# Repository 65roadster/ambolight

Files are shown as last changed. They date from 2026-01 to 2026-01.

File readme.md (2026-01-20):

# Ray's Retirement Nest Egg Calculator

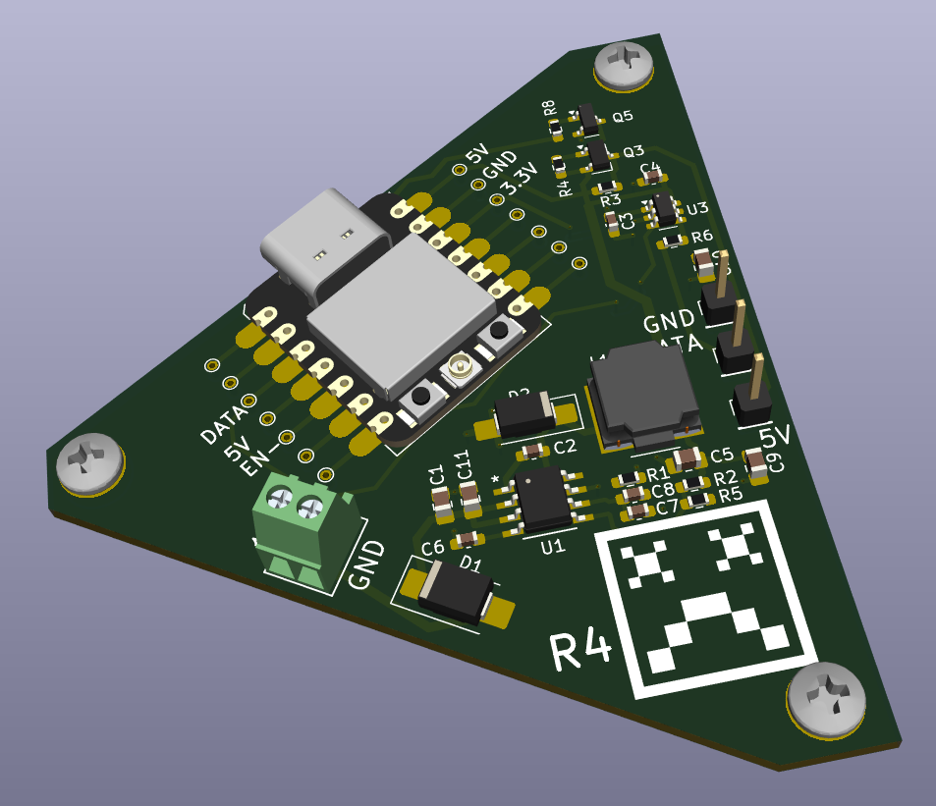
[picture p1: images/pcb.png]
<br />

## Overview
Drew bought an old ambulance to fix up into an RV. I wanted to contribute so I created an ESP32 controlled light.

The light has a ring of around 80- addressable RGBW LEDs.

The board accomodates 12V to 5V @ 3A switching supply to drive the LEDs using the TPS54331DDAR.

The ESP32 is programmed with WLED. 10 of these are controlled by Home Assistant.

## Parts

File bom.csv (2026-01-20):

Reference | Value | Datasheet | Footprint | Qty | DNP
C1,C7 | 22u | https://www.digikey.com/en/products/detail/samsung-electro-mechanics/CL31A226MOCLNNC/3888386 | Capacitor_SMD:C_1210_3225Metric_Pad1.33x2.70mm_HandSolder | 2
C2 | 1u | https://www.digikey.com/en/products/detail/samsung-electro-mechanics/CL31A226MOCLNNC/3888386 | Capacitor_SMD:C_1210_3225Metric_Pad1.33x2.70mm_HandSolder | 1
D2,D3,D4,D5,D6,D7,D8,D9,D10,D11,D12,D13,D14,D15,D16,D17,D18,D19,D20,D21,D22,D23,D24,D25 | IN-PI4818QAS5R5G5BPW | https://www.digikey.com/en/products/detail/inolux/in-pi4818qas5r5g5bpw/16964400 | 1-rjc-rv:LED_IN-PI42TASPRPGPB | 24
D26 | SMCJ28CA | https://www.digikey.com/en/products/detail/taiwan-semiconductor-corporation/SMCJ28CA/3042735 | Diode_SMD:D_SMC_Handsoldering | 1
J1,J2,J3 | 2061-602/998-404 | 2061-602/998-404 | 1-rjc-rv:WAGO_CONN2_2061-602_998-404_WAG | 3
Q1,Q3 | DMP3099L | https://www.digikey.com/en/products/detail/diodes-incorporated/DMP3099L-7/4471075 | Package_TO_SOT_SMD:TSOT-23_HandSoldering | 2
Q2 | BSS138-7-F | https://www.digikey.com/en/products/detail/diodes-incorporated/BSS138-7-F/717723 | Package_TO_SOT_SMD:TSOT-23_HandSoldering | 1
Q5 | MMBT3904 | https://www.digikey.com/en/products/detail/nexperia-usa-inc/MMBT3904-215/1156599 | Package_TO_SOT_SMD:SOT-23 | 1
R1,R2,R3,R18 | 10k | ~ | Resistor_SMD:R_1206_3216Metric_Pad1.30x1.75mm_HandSolder | 4
R4,R8 | 100k | ~ | Resistor_SMD:R_1206_3216Metric_Pad1.30x1.75mm_HandSolder | 2
R5,R7 | 0 | ~ | Resistor_SMD:R_1206_3216Metric_Pad1.30x1.75mm_HandSolder | 2
R6 | 300 | ~ | Resistor_SMD:R_1206_3216Metric_Pad1.30x1.75mm_HandSolder | 1
R17 | 40.2k | ~ | Resistor_SMD:R_1206_3216Metric_Pad1.30x1.75mm_HandSolder | 1
TP1,TP2,TP3,TP4,TP5,TP6,TP7,TP8,TP9,TP10,TP11 | TestPoint | ~ | 1-rjc-rv:TP_SMT_25mil | 11
U1 | TLVM23615RDNR | https://www.digikey.com/en/products/detail/texas-instruments/TLVM23615RDNR/18716429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 | 1-rjc-rv:TLVM23615RDNR | 1
U2 | MOUDLE-SEEEDUINO-XIAO-ESP32C3 |  | KM-ESP-Kit:SeeedStudio-MOUDLE14P-SMD-2.54-21X17.8MM | 1

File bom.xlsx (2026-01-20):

Reference | Value | Qty | Price Ea | Extended Price | Datasheet | Footprint | Qty | DNP
C1,C7 | 22u | 0 | $0.15 | $0.00 | https://www.digikey.com/en/products/detail/samsung-electro-mechanics/CL31A226MOCLNNC/3888386 | Capacitor_SMD:C_1210_3225Metric_Pad1.33x2.70mm_HandSolder | 2
C2 | 1u | 1 | $0.01 | $0.01 | https://www.digikey.com/en/products/detail/samsung-electro-mechanics/CL31A226MOCLNNC/3888386 | Capacitor_SMD:C_1210_3225Metric_Pad1.33x2.70mm_HandSolder | 1
D2,D3,D4,D5,D6,D7,D8,D9,D10,D11,D12,D13,D14,D15,D16,D17,D18,D19,D20,D21,D22,D23,D24,D25 | IN-PI4818QAS5R5G5BPW | 24 | $0.41 | $9.84 | https://www.digikey.com/en/products/detail/inolux/in-pi4818qas5r5g5bpw/16964400 | 1-rjc-rv:LED_IN-PI42TASPRPGPB | 24
D26 | SMCJ28CA | 0 |  |  | https://www.digikey.com/en/products/detail/taiwan-semiconductor-corporation/SMCJ28CA/3042735 | Diode_SMD:D_SMC_Handsoldering | 1
J1,J2,J3 | 2061-602/998-404 | 0 |  |  | 2061-602/998-404 | 1-rjc-rv:WAGO_CONN2_2061-602_998-404_WAG | 3
Q1,Q3 | DMP3099L | 1 | $0.18 | $0.18 | https://www.digikey.com/en/products/detail/diodes-incorporated/DMP3099L-7/4471075 | Package_TO_SOT_SMD:TSOT-23_HandSoldering | 2
Q2 | BSS138-7-F | 1 | $0.11 | $0.11 | https://www.digikey.com/en/products/detail/diodes-incorporated/BSS138-7-F/717723 | Package_TO_SOT_SMD:TSOT-23_HandSoldering | 1
Q5 | MMBT3904 | 1 | $0.05 | $0.05 | https://www.digikey.com/en/products/detail/nexperia-usa-inc/MMBT3904-215/1156599 | Package_TO_SOT_SMD:SOT-23 | 1
R1,R2,R3,R18 | 10k | 5 | $0.01 | $0.05 | ~ | Resistor_SMD:R_1206_3216Metric_Pad1.30x1.75mm_HandSolder | 4
R4,R8 | 100k | 0 |  | $0.00 | ~ | Resistor_SMD:R_1206_3216Metric_Pad1.30x1.75mm_HandSolder | 2
R5,R7 | 0 | 0 |  | $0.00 | ~ | Resistor_SMD:R_1206_3216Metric_Pad1.30x1.75mm_HandSolder | 2
R6 | 300 | 0 |  | $0.00 | ~ | Resistor_SMD:R_1206_3216Metric_Pad1.30x1.75mm_HandSolder | 1
R17 | 40.2k | 0 |  | $0.00 | ~ | Resistor_SMD:R_1206_3216Metric_Pad1.30x1.75mm_HandSolder | 1
TP1,TP2,TP3,TP4,TP5,TP6,TP7,TP8,TP9,TP10,TP11 | TestPoint | 0 |  | $0.00 | ~ | 1-rjc-rv:TP_SMT_25mil | 11
U1 | TLVM23615RDNR | 0 |  | $0.00 | https://www.digikey.com/en/products/detail/texas-instruments/TLVM23615RDNR/18716429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 | 1-rjc-rv:TLVM23615RDNR | 1
U2 | MOUDLE-SEEEDUINO-XIAO-ESP32C3 | 1 | $5.00 | $5.00 |  | KM-ESP-Kit:SeeedStudio-MOUDLE14P-SMD-2.54-21X17.8MM | 1
 | PCB | 1 | $5.00 | $5.00
 |  |  | Total | $20.24

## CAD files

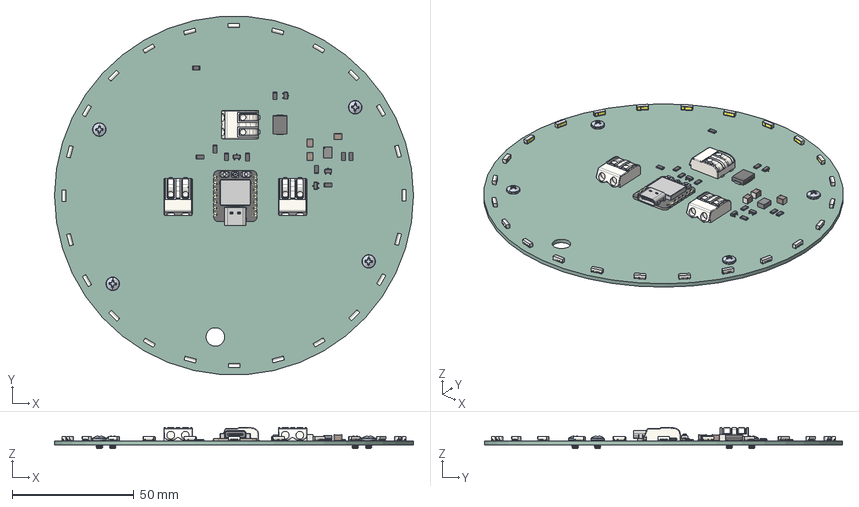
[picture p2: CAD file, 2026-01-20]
R0/abmolight.step
147.3 x 146.9 x 8.63 mm
2061-602/998-404 x 3
PI4818QAS5R5G5B5W x 24
90272A103 x 4
R_1206_3216Metric x 10
C_1210_3225Metric x 3
TSOT_23 x 3
TPSM365R6RDNR
SOT_23
Seeed Studio XIAO-ESP32-C3 v15
D_SMC
_autosave-rv_light_PCB

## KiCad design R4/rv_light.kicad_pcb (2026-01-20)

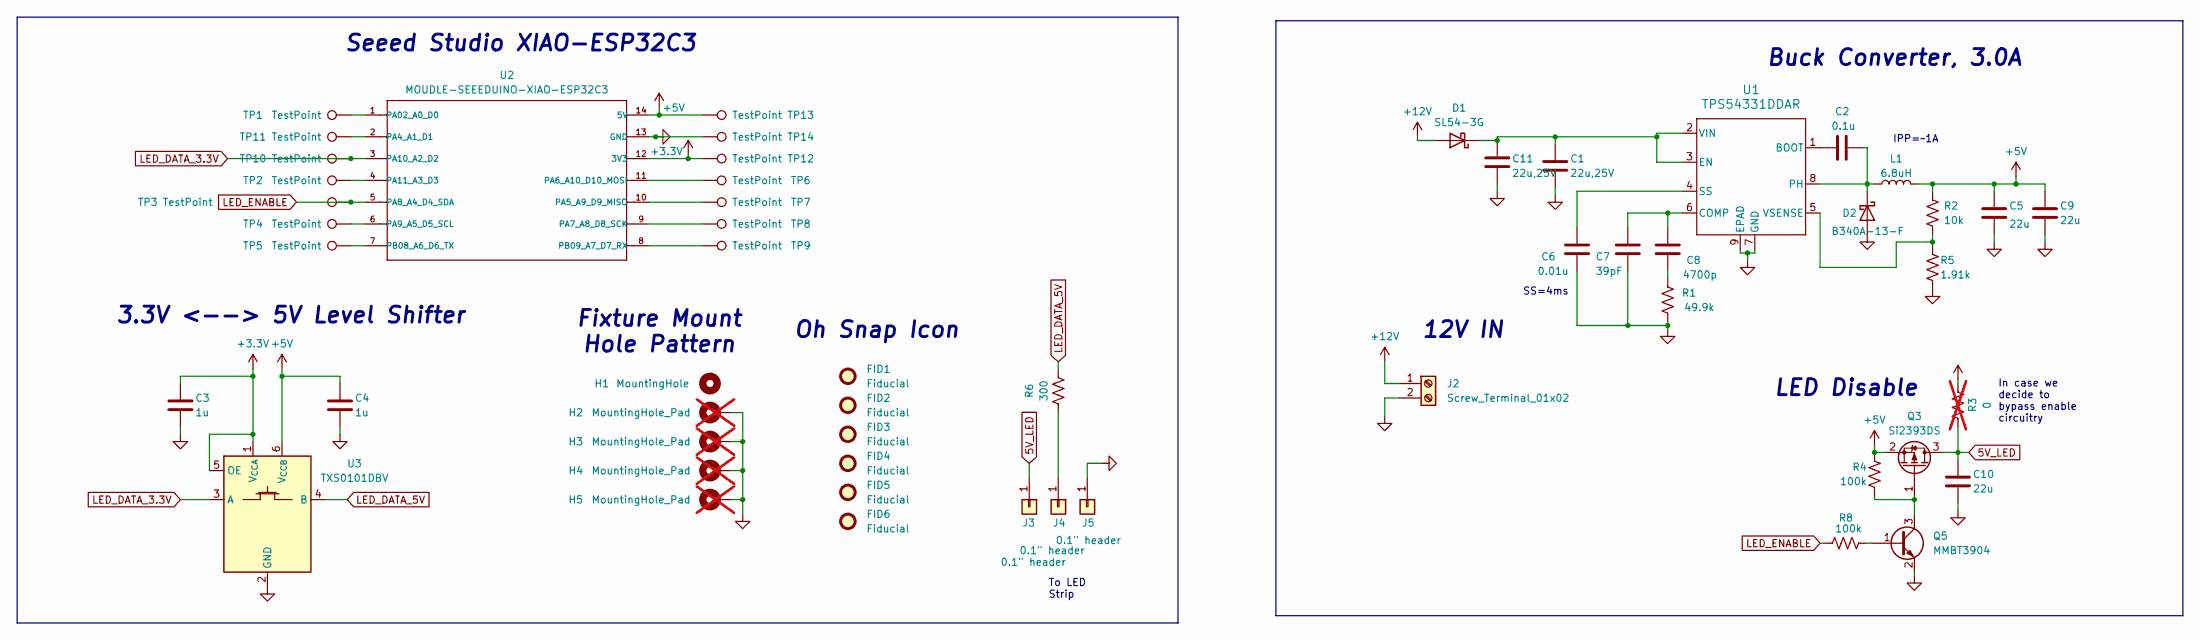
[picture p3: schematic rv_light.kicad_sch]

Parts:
C1, C11: 22u,25V; C_0805_2012Metric_Pad1.18x1.45mm_HandSolder
C2: 0.1u; C_0603_1608Metric_Pad1.08x0.95mm_HandSolder
C3, C4: 1u; C_0603_1608Metric_Pad1.08x0.95mm_HandSolder
C5, C9, C10: 22u; C_0805_2012Metric_Pad1.18x1.45mm_HandSolder
C6: 0.01u; C_0603_1608Metric_Pad1.08x0.95mm_HandSolder
C7: 39pF; C_0603_1608Metric_Pad1.08x0.95mm_HandSolder
C8: 4700p; C_0603_1608Metric_Pad1.08x0.95mm_HandSolder
D1: SL54-3G; D_SMB_Handsoldering
D2: B340A-13-F; D_SMA_Handsoldering
FID1, FID2, FID3, FID4, FID5, FID6: Fiducial; brokedit_icon_750x750
H1: MountingHole; Mount-Hole-#4-NoPad
H2, H3, H4, H5: MountingHole_Pad; Mount-Hole-#4; not fitted
J2: Screw_Terminal_01x02; CONN_OSTVN02A150_OST
J3, J4, J5: 0.1" header; PinHeader_1x01_P2.54mm_Vertical
L1: 6.8uH; L_Bourns_SRN8040TA
Q3: Si2393DS; TSOT-23
Q5: MMBT3904; SOT-23
R1: 49.9k; R_0603_1608Metric_Pad0.98x0.95mm_HandSolder
R2: 10k; R_0603_1608Metric_Pad0.98x0.95mm_HandSolder
R3: 0; R_0603_1608Metric_Pad0.98x0.95mm_HandSolder; not fitted
R4, R8: 100k; R_0603_1608Metric_Pad0.98x0.95mm_HandSolder
R5: 1.91k; R_0603_1608Metric_Pad0.98x0.95mm_HandSolder
R6: 300; R_0603_1608Metric_Pad0.98x0.95mm_HandSolder
TP1, TP2, TP3, TP4, TP5, TP6, TP7, TP8, TP9, TP10, TP11, TP12, TP13, TP14: TestPoint; TP_Wire-26ga
U1: TPS54331DDAR; DDA8_3X2P13-M
U2: MOUDLE-SEEEDUINO-XIAO-ESP32C3; SeeedStudio-MOUDLE14P-SMD-2.54-21X17.8MM
U3: TXS0101DBV; SOT-23-6

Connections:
5V_LED: C10.1, J3.1, Q3.3 (D), R3.1
+3.3V: C3.1, TP12.1, U2.12 (3V3), U3.1 (V_{CCA}), U3.5 (OE)
+5V: C4.1, C5.1, C9.1, L1.2, Q3.2 (S), R2.1, R3.2, R4.1, TP13.1, U2.14 (5V), U3.6 (V_{CCB})
+12V: D1.2 (A), J2.1
GND: C1.2, C3.2, C4.2, C5.2, C6.2, C7.2, C9.2, C10.2, C11.2, D2.2 (A), H2.1, H3.1, H4.1, H5.1, J2.2, J5.1, Q5.2 (E), R1.2, R5.2, TP14.1, U1.7 (GND), U1.9 (EPAD), U2.13 (GND), U3.2 (GND)
LED_DATA_3.3V: TP10.1, U2.3 (PA10_A2_D2), U3.3 (A)
LED_DATA_5V: R6.1, U3.4 (B)
LED_ENABLE: R8.1, TP3.1, U2.5 (PA8_A4_D4_SDA)
unnamed: C8.2, R1.1
unnamed: C1.1, C11.1, D1.1 (K), U1.2 (VIN), U1.3 (EN)
unnamed: C2.1, D2.1 (K), L1.1, U1.8 (PH)
unnamed: J4.1, R6.2
unnamed: Q3.1 (G), Q5.3 (C), R4.2
unnamed: Q5.1 (B), R8.2
unnamed: C2.2, U1.1 (BOOT)
unnamed: C7.1, C8.1, U1.6 (COMP)
unnamed: C6.1, U1.4 (SS)
unnamed: R2.2, R5.1, U1.5 (VSENSE)
unnamed: TP1.1, U2.1 (PA02_A0_D0)
unnamed: TP11.1, U2.2 (PA4_A1_D1)
unnamed: TP7.1, U2.10 (PA5_A9_D9_MISO)
unnamed: TP6.1, U2.11 (PA6_A10_D10_MOSI)
unnamed: TP8.1, U2.9 (PA7_A8_D8_SCK)
unnamed: TP4.1, U2.6 (PA9_A5_D5_SCL)
unnamed: TP2.1, U2.4 (PA11_A3_D3)
unnamed: TP5.1, U2.7 (PB08_A6_D6_TX)
unnamed: TP9.1, U2.8 (PB09_A7_D7_RX)

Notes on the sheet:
IPP=~1A
LED Disable
Buck Converter, 3.0A
Oh Snap Icon
In case we decide to bypass enable circuitry
12V IN
Seeed Studio XIAO-ESP32C3
SS=4ms
Fixture Mount Hole Pattern
To LED Strip
3.3V <--> 5V Level Shifter

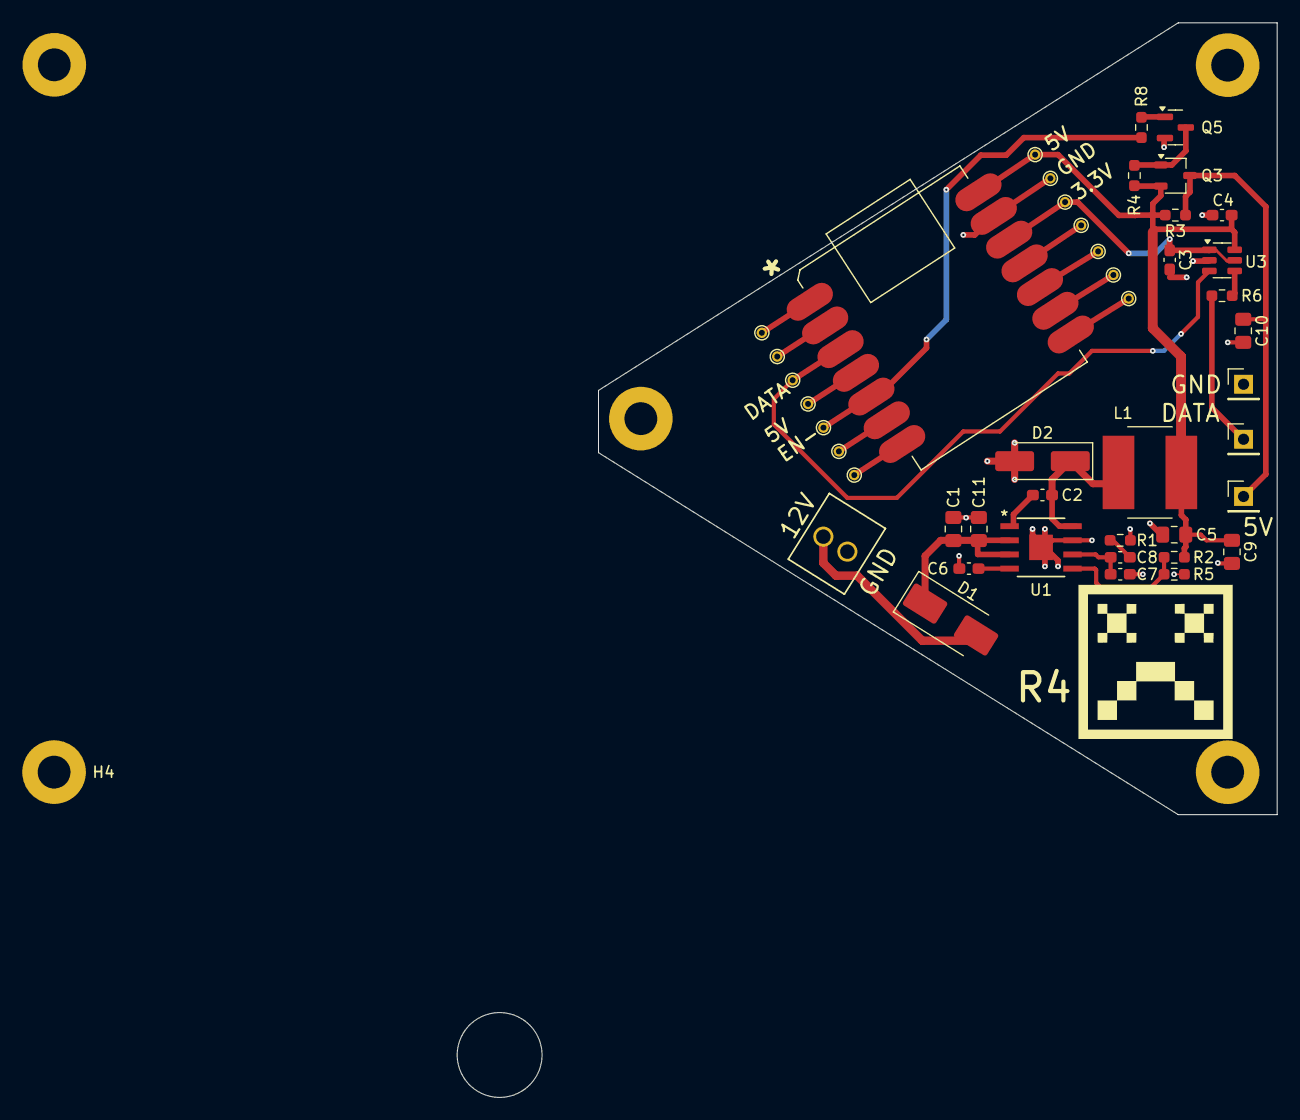
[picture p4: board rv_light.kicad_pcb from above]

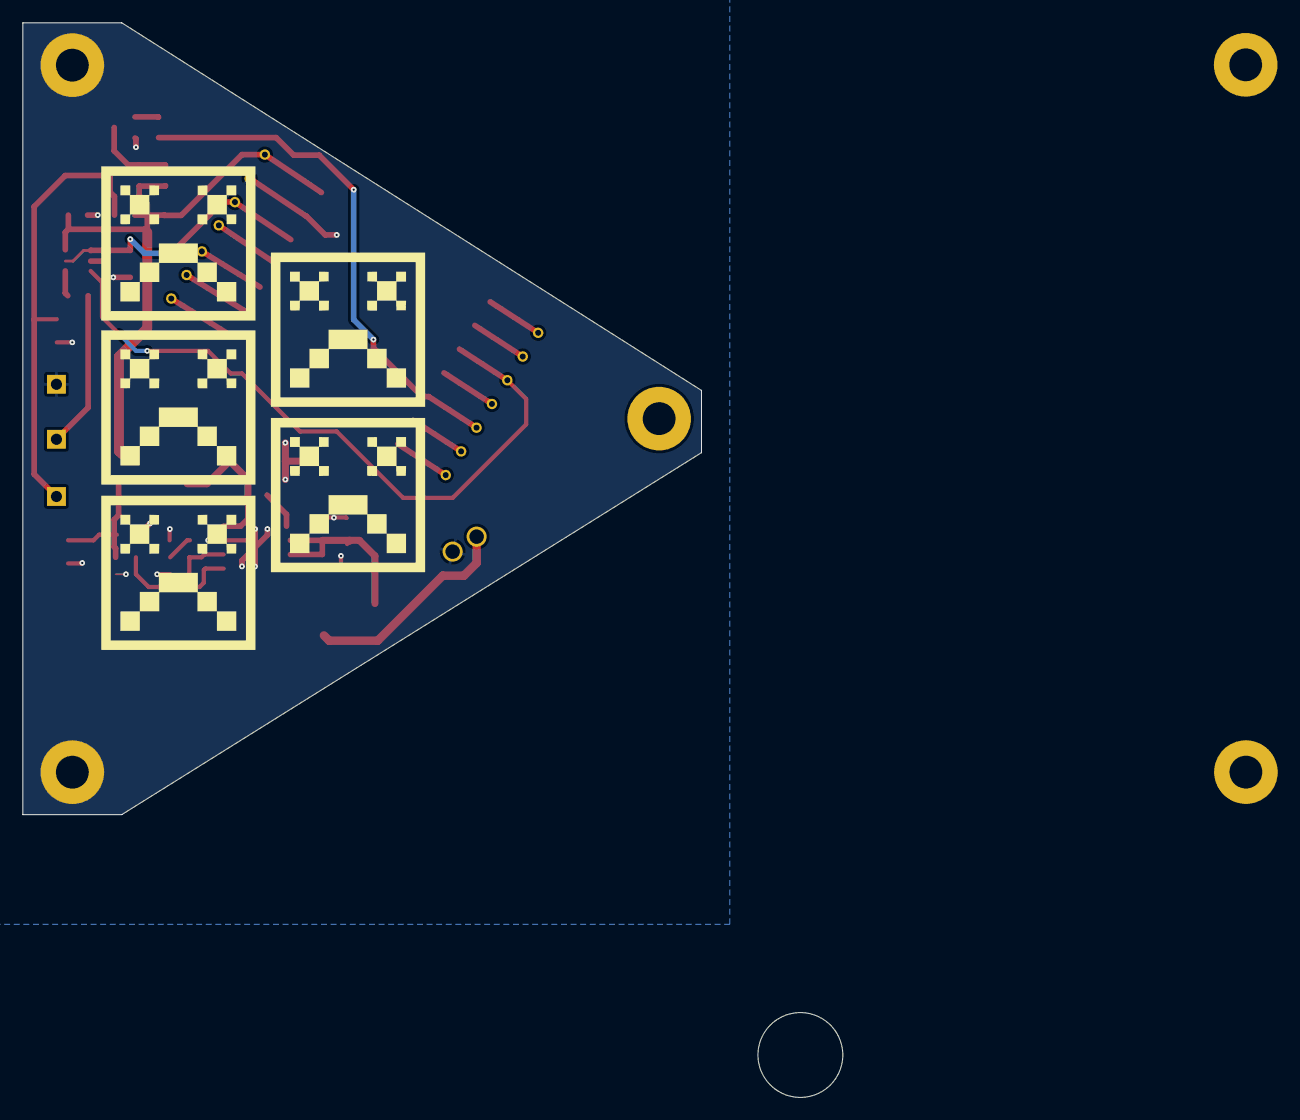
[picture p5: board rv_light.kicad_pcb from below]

Board: 2 copper layers, 61.0 x 71.1 mm, 55 parts (5 on the bottom side), 27 nets.
